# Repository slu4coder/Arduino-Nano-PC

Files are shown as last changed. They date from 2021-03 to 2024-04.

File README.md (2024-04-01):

# Arduino Nano Personal Computer - Squeezing Water from a Stone

I am pushing the limits of how much compute you can get out of an Arduino Nano:

        o 320x200 pixels of monochrome VGA output (optional: 16 row colors)

        o PS/2 keyboard readout

        o requires only 1(!) logic IC 74HC166

bild

# HOW TO USE THE 'NANO HOME COMPUTER'

1. Set the Nano's fuses for output of the 16MHz system clock on pin D8 (see appendix A below).

2. Copy the library files 'os.h' and 'os.S' into a folder '../Arduino/libraries/os'.

3. Start a new sketch with '#include <os.h>'. The following global variables and functions are available:

        int os::frames                                        built-in 16-bit 60Hz frame counter
  
        byte os::vram[25][40]                                 character video RAM array
  
        byte os::cram[25]                                     row color RAM array, available colors are:
  
                                                              WHITE, BLACK, GRAY, RED, GREEN, YELLOW, BLUE, MAGENTA, CYAN,
                                                    
                                                              DKGRAY, DKRED, DKGREEN, DKYELLOW, DKBLUE, DKMAGENTA, DKCYAN.
                                                    
        os::text(String s, byte x, byte y, byte col = 0)      prints text at screen position (x, y), col = 0: don't set row color
  
        os::fill(char c = 32)                                 fills the video RAM with character c
  
        os::scroll()                                          scrolls the video RAM one step upwards
  
        os::wait(int n)                                       waits for n frames
  
        byte os::getkey()                                     returns keystroke ASCII code (none: 0)
  
4. 26KB FLASH (1KB SRAM) of the Nano's 30KB FLASH (2KB SRAM) are usable, respectively.
   To save SRAM, define constant variables in FLASH memory by adding PROGMEM to the data type.
   Constant string arguments can be defined in FLASH by using the F("...") macro.

5. Have fun!

APPENDIX

A. Setting Arduino Nano's fuse bytes via ISP (in-situ programming) for output of system CLK

  o Connect two Arduino Nanos in the following way (programmer -> target):
    D13 -> D13, D12 -> D12, D11 -> D11, D10 -> RESET, 5V -> 5V, GND -> GND
    
  o Arduino IDE: Upload sketch 'examples/ArduinoISP' into programmer and select 'Tools/Programmer/Arduino as ISP'.
  
  o Open the file 'C:\Program Files (x86)\Arduino\hardware\arduino\avr\boards.txt'.
  
  o In section '## Arduino Nano w/ ATmega328P' (line 141), change line 149 'nano.menu.cpu.atmega328.bootloader.low_fuses=0xFF'
    (default) to '...=0xBF' (output system CLK on Pin D8 (B0)) and save the file.
    
  o Close and re-open the Arduino IDE for the changes to become active.
  
  o Select target board: 'Arduino Nano', processor: 'AtMega328P' and 'Tools/Burn bootloader'.

B. Hardware

  Pin A0 (C0):     keyboard input CLK
  
  Pin A1 (C1):     keyboard input DAT
  
  Pin A2-5 (C2-5): 4-bit color output to 74HC08 (optional)
  
  Pin D0-7 (D0-7): 8-bit pixel output to 74HC166
  
  Pin D8 (B0):     CLKO (16MHz system clock output)
  
  Pin D9 (B1):     unused
  
  Pin D10 (B2):    /VSYNC VGA (timer1, every 1/60s)
  
  Pin D11 (B3):    /PE 74166 pixel shift register synchroneous parallel load on rising edge of CP
  
  Pin D12 (B4):    /HSYNC VGA (inside ISR, every 32µs)
  
  Pin D13 (B5):    LED

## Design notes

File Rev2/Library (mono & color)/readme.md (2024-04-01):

# Header Library

Copy the folder 'os' containing the header library files to '/Arduino/libraries/'.

See 'Arduino IDE/File/Preferences' if you are unsure where to find it).
Be sure to start a new sketch with '#include <os.h>'.

Have fun!

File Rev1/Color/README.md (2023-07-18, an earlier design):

# Arduino Nano Personal Computer 1

16-color mod of my original 'Arduino Nano PC' revision 1 with VGA output and PS/2 keyboard input
running on a single Arduino NANO and 5 additional logic ICs.

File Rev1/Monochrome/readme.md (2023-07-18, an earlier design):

# Arduino Nano PC 1

Original monochrome version using 4 additional logic ICs.

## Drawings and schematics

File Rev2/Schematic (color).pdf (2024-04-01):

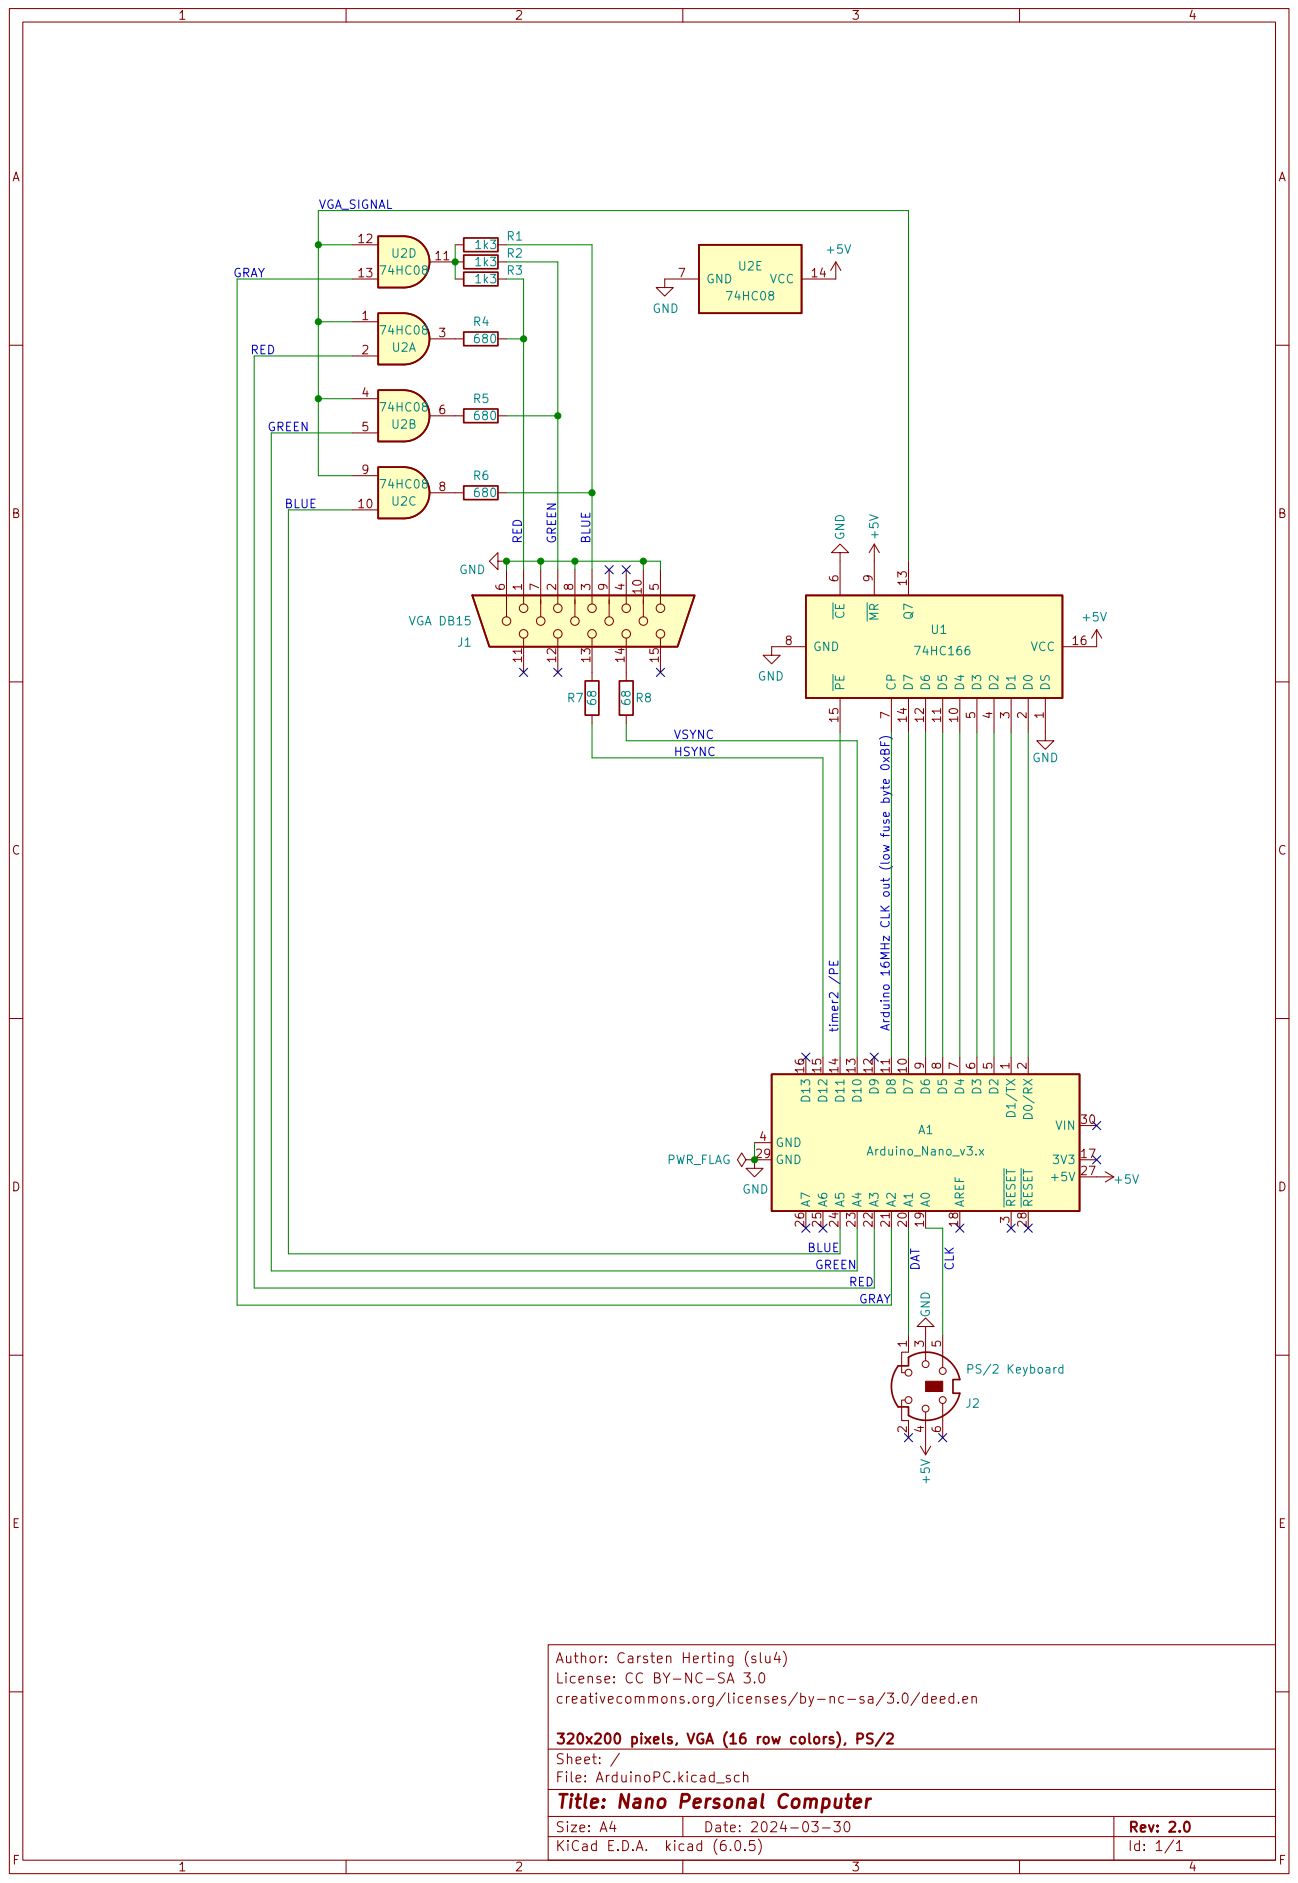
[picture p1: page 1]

2 A1 20 A2 21 A3 22 A4 23 A5 24 A6 25 A7 26 +5V 27 ~{RESET} 28 GND 29 ~{RESET} 3 VIN 30 GND 4 D2

License: CC BY-NC-SA 3.0 Author: Carsten Herting (slu4)

creativecommons.org/licenses/by-nc-sa/3.0/deed.en

File: ArduinoPC.kicad_sch Sheet: / 320x200 pixels, VGA (16 row colors), PS/2

Id: 1/1 Title: Nano Personal Computer

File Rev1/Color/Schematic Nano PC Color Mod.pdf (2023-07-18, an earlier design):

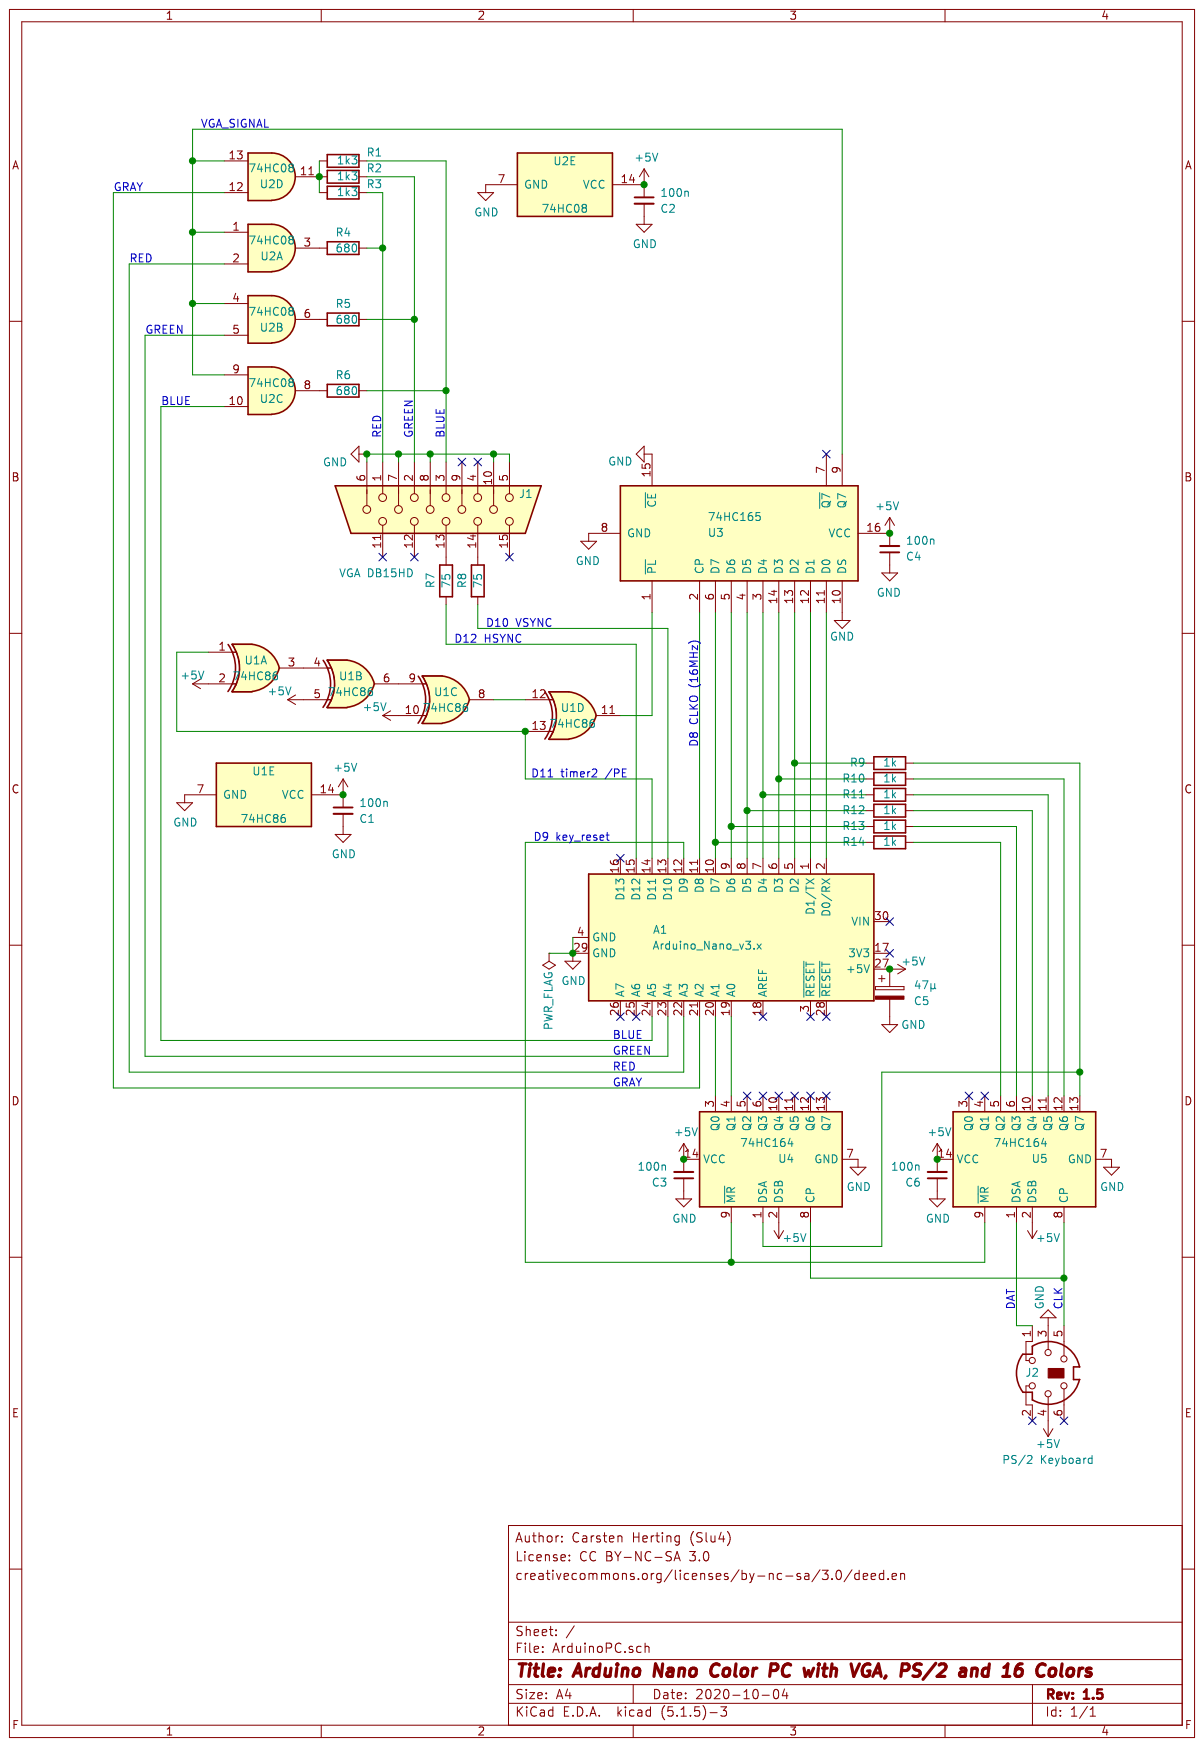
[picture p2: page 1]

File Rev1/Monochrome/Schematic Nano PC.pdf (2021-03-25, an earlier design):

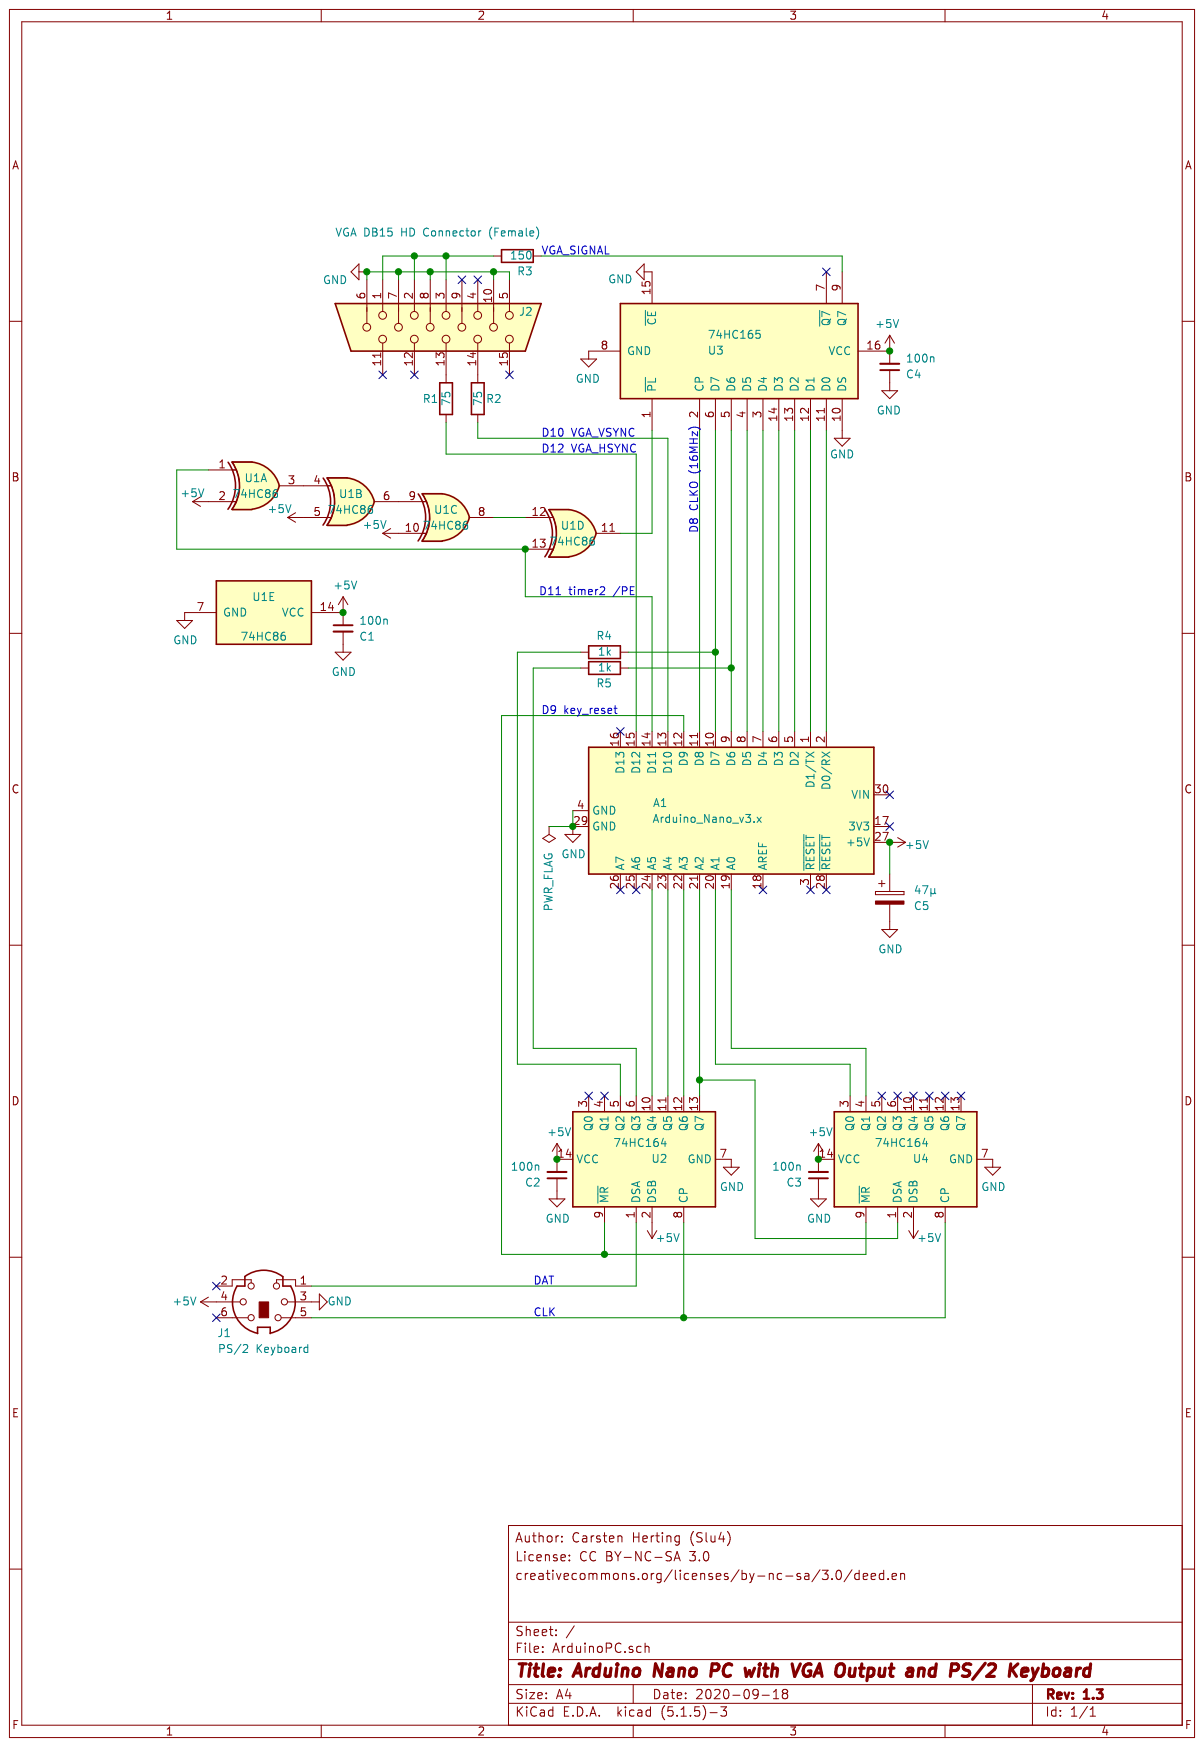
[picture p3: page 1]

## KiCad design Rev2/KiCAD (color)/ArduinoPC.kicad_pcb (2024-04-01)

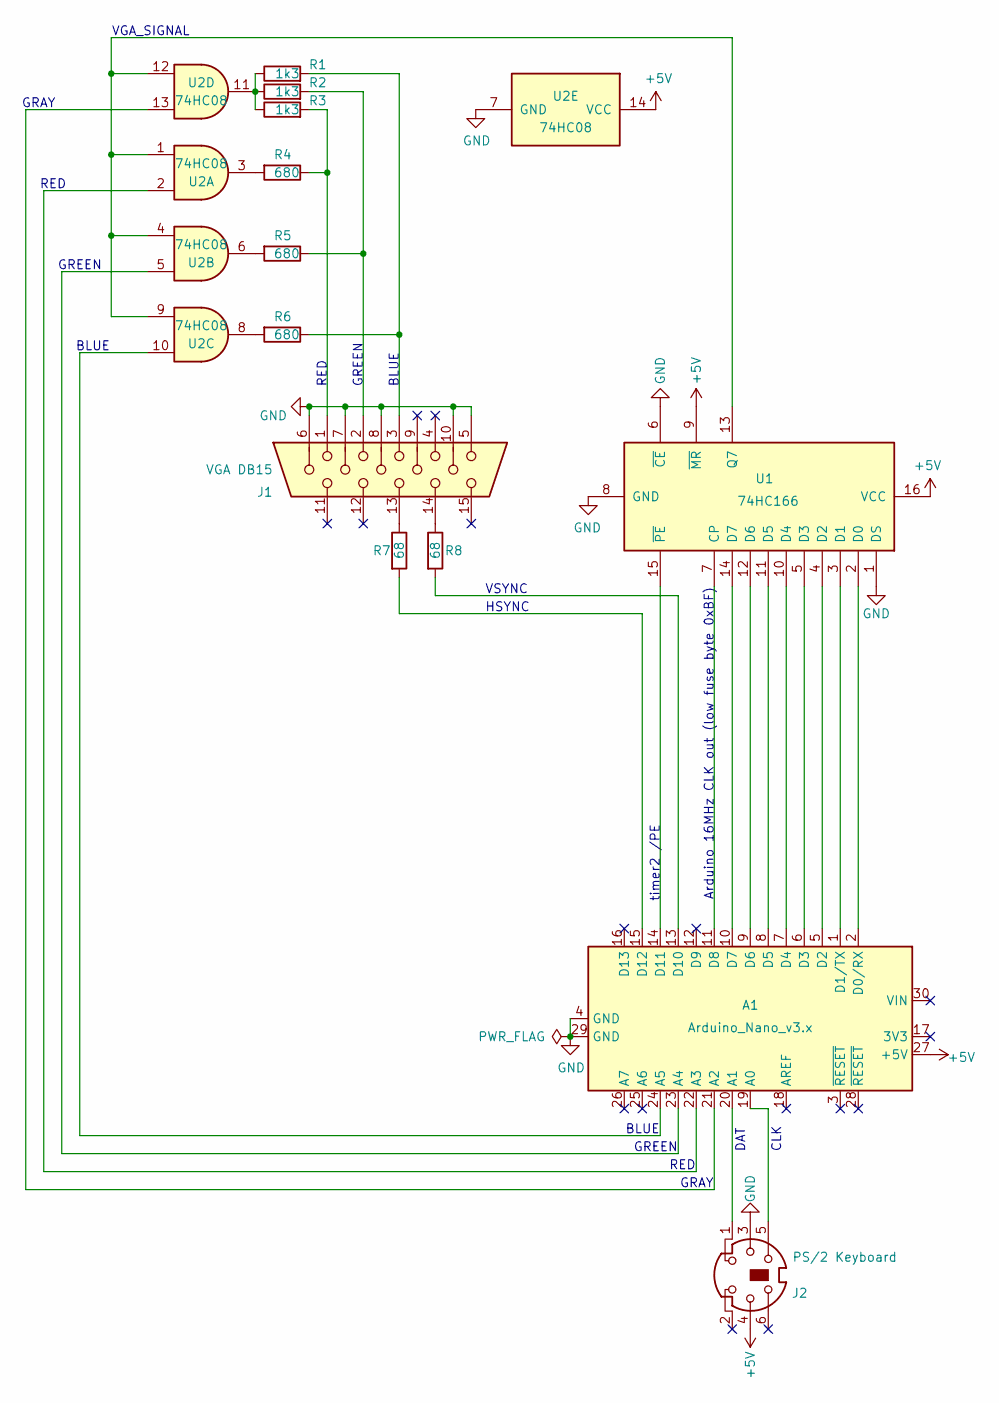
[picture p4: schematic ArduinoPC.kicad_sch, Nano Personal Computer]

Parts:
A1: Arduino_Nano_v3.x; Arduino_Nano
J1: VGA DB15; VGA DSUB15HD_female
J2: PS/2 Keyboard; FP_MINI_DIN_6_PS2
R1, R2, R3: 1k3; R_Axial_DIN0207_L6.3mm_D2.5mm_P2.54mm_Vertical
R4, R5, R6: 680; R_Axial_DIN0207_L6.3mm_D2.5mm_P2.54mm_Vertical
R7, R8: 68; R_Axial_DIN0207_L6.3mm_D2.5mm_P2.54mm_Vertical
U1: 74HC166; DIP-16_W7.62mm
U2: 74HC08; DIP-14_W7.62mm

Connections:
+5V: A1.27 (+5V), J2.4, U1.9 (~MR), U1.16 (VCC), U2.14 (VCC)
GND: A1.4 (GND), A1.29 (GND), J1.5, J1.6, J1.7, J1.8, J1.10, J2.3, U1.1 (DS), U1.6 (~CE), U1.8 (GND), U2.7 (GND)
unnamed: A1.1 (D1/TX), U1.3 (D1)
unnamed: A1.2 (D0/RX), U1.2 (D0)
unnamed: A1.5 (D2), U1.4 (D2)
unnamed: A1.6 (D3), U1.5 (D3)
unnamed: A1.7 (D4), U1.10 (D4)
unnamed: A1.8 (D5), U1.11 (D5)
unnamed: A1.9 (D6), U1.12 (D6)
unnamed: A1.10 (D7), U1.14 (D7)
unnamed: A1.11 (D8), U1.7 (CP)
unnamed: A1.13 (D10), R8.2
unnamed: A1.14 (D11), U1.15 (~PE)
unnamed: A1.15 (D12), R7.2
unnamed: A1.19 (A0), J2.5
unnamed: A1.20 (A1), J2.1
unnamed: A1.21 (A2), U2.13
unnamed: A1.22 (A3), U2.2
unnamed: A1.23 (A4), U2.5
unnamed: A1.24 (A5), U2.10
unnamed: J1.1, R3.2, R4.1
unnamed: J1.2, R2.2, R5.1
unnamed: J1.3, R1.2, R6.1
unnamed: J1.13, R7.1
unnamed: J1.14, R8.1
unnamed: R1.1, R2.1, R3.1, U2.11
unnamed: R4.2, U2.3
unnamed: R5.2, U2.6
unnamed: R6.2, U2.8
unnamed: U1.13 (Q7), U2.1, U2.4, U2.9, U2.12

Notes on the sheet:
GREEN
RED
BLUE
VGA_SIGNAL
GRAY
timer2 /PE
Arduino 16MHz CLK out (low fuse byte 0xBF)
CLK
DAT
VSYNC
HSYNC

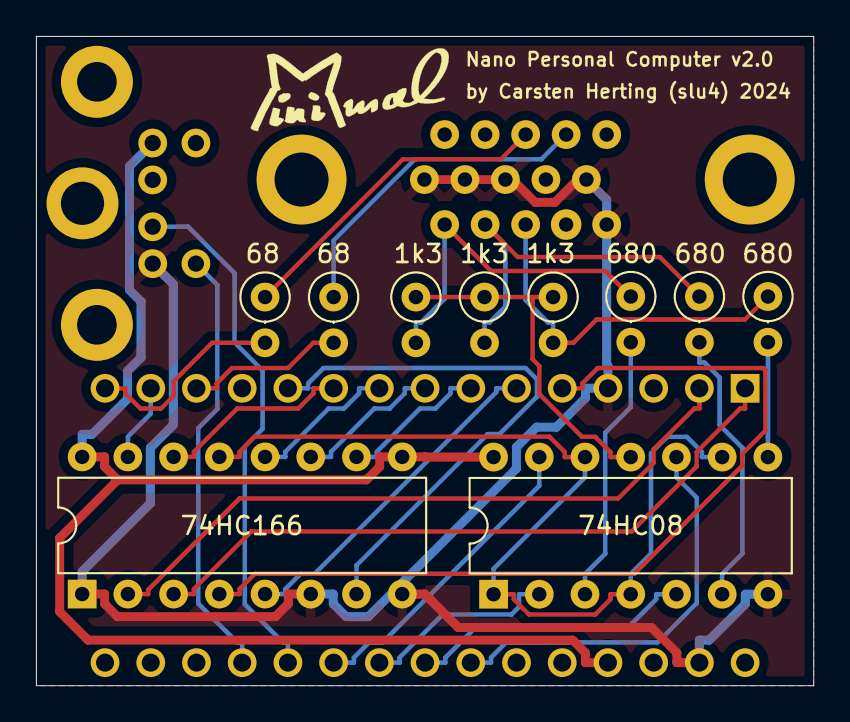
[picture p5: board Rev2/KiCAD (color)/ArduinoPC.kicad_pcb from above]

Board: 2 copper layers, 43.2 x 36.1 mm, 13 parts (0 on the bottom side), 30 nets.

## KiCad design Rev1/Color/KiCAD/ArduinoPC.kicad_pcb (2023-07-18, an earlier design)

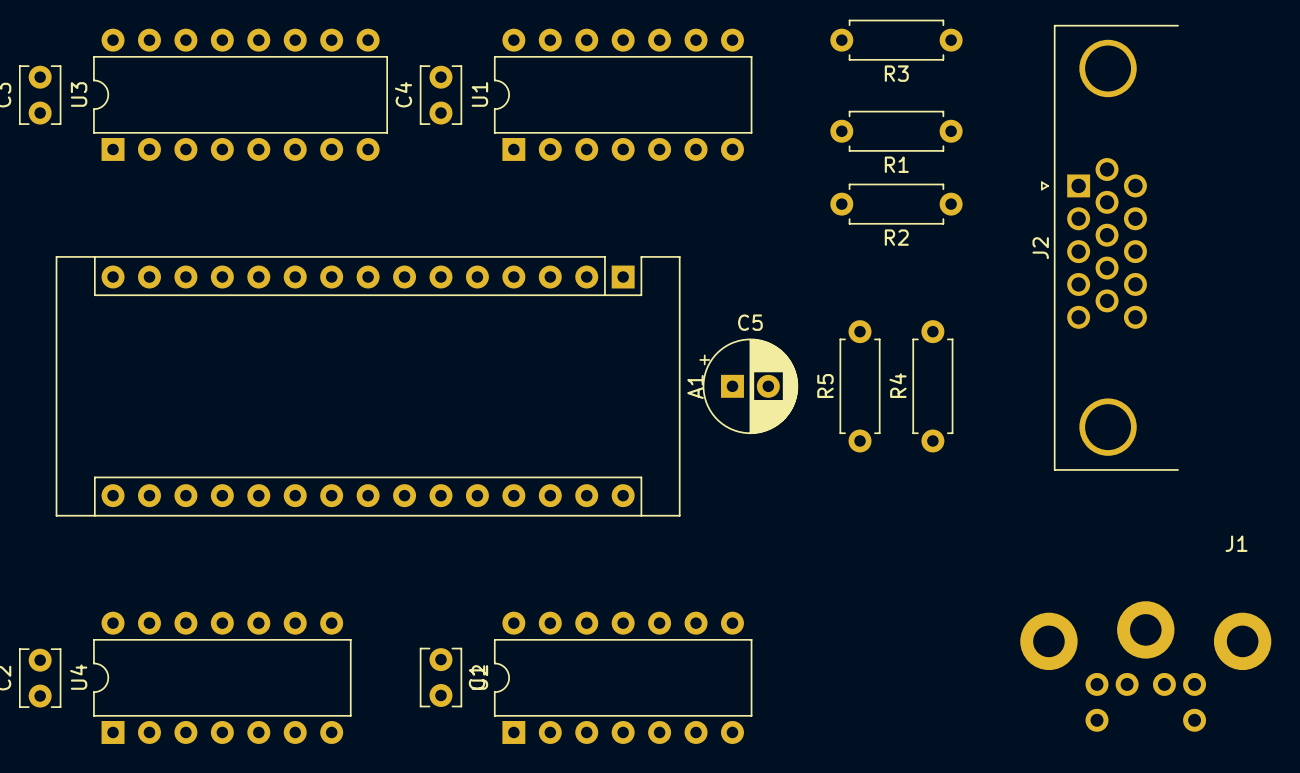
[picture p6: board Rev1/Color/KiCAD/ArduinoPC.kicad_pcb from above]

Board: 2 copper layers, 17 parts (0 on the bottom side), 33 nets, no tracks yet.

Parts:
A1: Arduino_Nano_v3.x; Arduino_Nano
C1, C2, C3, C4: 100n; C_Disc_D3.8mm_W2.6mm_P2.50mm
C5: 47µ; CP_Radial_D6.3mm_P2.50mm
J1: PS/2 Keyboard; FP_MINI_DIN_6_PS2
J2: VGA DB15 HD Connector (Female); DSUB-15-HD_Female_Horizontal_P2.29x1.98mm_EdgePinOffset3.03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
R1, R2: 68; R_Axial_DIN0207_L6.3mm_D2.5mm_P7.62mm_Horizontal
R3, R4, R5: 220; R_Axial_DIN0207_L6.3mm_D2.5mm_P7.62mm_Horizontal
U1: 74HC86; DIP-14_W7.62mm
U2, U4: 74HC164; DIP-14_W7.62mm
U3: 74HC165; DIP-16_W7.62mm

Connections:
+5V: A1.27, C1.1, C2.2, C3.2, C4.2, C5.1, J1.4, U1.2, U1.5, U1.10, U1.14, U2.2, U2.14, U3.16, U4.2, U4.14
GND: A1.4, A1.29, C1.2, C2.1, C3.1, C4.1, C5.2, J1.3, J2.5, J2.6, J2.7, J2.8, J2.10, U1.7, U2.7, U3.8, U3.10, U3.15, U4.7
unnamed: A1.1, U3.12
unnamed: A1.2, U3.11
unnamed: A1.5, U3.13
unnamed: A1.6, U3.14
unnamed: A1.7, U3.3
unnamed: A1.8, U3.4
unnamed: A1.9, R5.2, U3.5
unnamed: A1.10, R4.2, U3.6
unnamed: A1.11, U3.2
unnamed: A1.12, U2.9, U4.9
unnamed: A1.13, R2.2
unnamed: A1.14, U1.1, U1.13
unnamed: A1.15, R1.2
unnamed: A1.19, U4.4
unnamed: A1.20, U4.3
unnamed: A1.21, U2.13, U4.1
unnamed: A1.22, U2.12
unnamed: A1.23, U2.11
unnamed: A1.24, U2.10
unnamed: J1.1, U2.1
unnamed: J1.5, U2.8, U4.8
unnamed: J2.1, J2.2, J2.3, R3.1
unnamed: J2.13, R1.1
unnamed: J2.14, R2.1
unnamed: R3.2, U3.9
unnamed: R4.1, U2.5
unnamed: R5.1, U2.6
unnamed: U1.3, U1.4
unnamed: U1.6, U1.9
unnamed: U1.11, U3.1
unnamed: U1.8, U1.12

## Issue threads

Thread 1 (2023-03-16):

Working with 74HC166N shift register

PeterKL3, 2023-03-16:
Hi, thanks for the terrific work.
I want to ask you how I can use your code with the other shift register you sometimes use, the 74HC166. When I use it with this code and without the XOR-Gates, it displays only every other row on the VGA monitor. Is this a timing issues? Thanks a lot. Peter

slu4coder, 2023-07-22:
Hi Peter, the Nano PC Revision 1 relies on 74HC165. Please do not use 74HC166.

I am currently working on an update (Revision 2): 1x Nano + 1x 74HC166 = "full PC" with VGA and PS/2
Watch out for my upcoming YouTube video! Cheers!

Closed 2023-07-22.

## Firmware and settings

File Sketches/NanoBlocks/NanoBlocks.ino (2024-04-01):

#include <os.h> // copy the files 'os.h' and 'os.S' into the folder '.../Arduino/libraries/os'

char state, x, y, waiting;
int score, high = 0;
char shape[10];       // holding the current shape (with offset)
const char minos[7][10] PROGMEM = { { 0, 0, 1, 0, 0, -1, 1, -1,   0, 1 },     // Quadrat (with SRS offset)
                                    { -1, -1, 0, -1, 0, 0, 1, 0,  0, 0 },     // Z
                                    { -1, 0, 0, 0, 0, -1, 1, -1,  0, 0 },     // neg. Z
                                    { -1, 0, 0, 0, 1, 0, 2, 0,    0, 1 },     // I
                                    { -1, 0, 0, 0, 1, 0, 0, -1,   0, 0 },     // Podest
                                    { -1, -1, -1, 0, 0, 0, 1, 0,  0, 0 },     // L
                                    { -1, 0, 0, 0, 1, 0, 1, -1,   0, 0 }  };  // neg. L

void drawintro()
{
  os::fill();
  os::text(F("A R D U I N O   B L O C K S"), 6, 10, CYAN);
  os::text(F("Press  SPACE"), 13, 23, YELLOW);
}

void drawfield()
{
  os::fill();
  for (byte i=0; i<5; i++) os::text(F("<!..........!>"), 12, i, CYAN);
  for (byte i=5; i<20; i++) os::text(F("<!..........!>"), 12, i, WHITE);
  os::text(F("<!==========!>"), 12, 20, CYAN);
  os::text(F("  VVVVVVVVVV  "), 12, 21, MAGENTA);
  os::text(F("SCORE 0"), 0, 0, GREEN);
  os::text(F("HIGH"), 27, 0);    
  os::text(String(high, DEC), 32, 0);
  os::text(F("CONTROLS"), 0, 3, CYAN);
  os::text(F("A - Left"), 0, 5, GRAY);
  os::text(F("D - Right"), 0, 6, GRAY);
  os::text(F("W - Rotate"), 0, 7, GRAY);
  os::text(F("S - Drop"), 0, 8, GRAY);
}

boolean testShape(char x, char y)
{
  boolean isok = true;
  for (char i=0; i<8; i+=2)
  {
    if (x + shape[i] < 14+0 || x + shape[i] > 14+9) { isok = false; break; }         // linker / rechter Rand
    if (y + shape[i+1] < 0 || y + shape[i+1] > 19) { isok = false; break; }        // oberer / unterer Rand
    if (os::vram[y + shape[i+1]][x + shape[i]] != '.') { isok = false; break; }   // Spielfeld
  }
  return isok;
}

void newShape()
{
  byte m = random(7);
  for (char i=0; i<10; i++) shape[i] = pgm_read_byte_near(&minos[m][i]);
  x = 14+4; y = 1;
  if (testShape(x, y)) drawShape('#');
  else
  {
    os::text(F("GAME  OVER"), 14, 10, RED);
    os::text(F("Press  SPACE"), 13, 23, YELLOW);
    state = 2;
  }
}

void rotShape()
{
  char rotshape[10];
  for(char i=0; i<10; i+=2)
  {
    rotshape[i] = shape[i+1];
    rotshape[i+1] = -shape[i];
  }
  for (char i=0; i<10; i++) shape[i] = rotshape[i];
  x += shape[8]; y+= shape[9];  // add rotated offset correction
}

void drawShape(char c)
{
  for (char i=0; i<8; i+=2) os::vram[y + shape[i+1]][x + shape[i]] = c;        // Shape ins Feld schreiben  
}

void updateField()
{
  char anzrows = 0;                                                             // count the number of rows cleared
  for (char y=0; y<20; y++)                                                    // gehe alle Reihen durch
  {
    boolean rowfull = true;
    for(char x=14; x<14+10; x++) if (os::vram[y][x] == '.') rowfull = false;            // ist diese Reihe voll?
    if (rowfull)
    {
      anzrows++;
      for(char i=y; i>0; i--) for(char x=14; x<14+10; x++) os::vram[i][x] = os::vram[i-1][x];   // kopiere ab dieser Reihe alles nach unten
      for(char x=14; x<14+10; x++) os::vram[0][x] = '.';                                      // und lösche die obere Zeile
    }
  }
  switch (anzrows)
  {
    case 1: score += 40; break;
    case 2: score += 100; break;
    case 3: score += 200; break;
    case 4: score += 500; break;
  }
}

void setup()
{
  drawintro();
  state = 0;
}

void loop()
{ 
  int frame = os::frames;
  byte key = os::getkey();
  switch(state)
  {
    case 0:
      if (key == ' ')
      {
        randomSeed(os::frames); random();
        drawfield();
        newShape();
        waiting = 40; os::frames = 0; score = 0; state = 1;

      }
      break;
    case 1:
      if (key != 0)
      {
        if (key == 's') { waiting -= 40; score++; }
        else
        {
          drawShape('.');        // Shape ins Feld schreiben  
          switch (key)
          {
            case 'a':
              if (testShape(x-1, y)) x--;
              break;
            case 'd':
              if (testShape(x+1, y)) x++;
              break;
            case 'w':
              rotShape();                                               // drehe die Shape ccw
              if (testShape(x, y) == false)                             // prüfe, ob darunter KEIN Platz ist
              {
                if (testShape(x-1, y)) x--;                             // teste links
                else if (testShape(x+1, y)) x++;                        // teste rechts
                else if (testShape(x-2, y)) x-=2;                       // Sonderfall langer Balken
                else if (testShape(x+2, y)) x+=2;
                else { rotShape(); rotShape(); rotShape(); }            // geht nicht => Drehung rückgängig machen          
              }
              break;            
          }
          drawShape('#');        // Shape ins Feld schreiben  
        }
      }
      if (waiting-- < 0)                                          // FALLEN
      {
        waiting += (40 - (os::frames >> 9));
        drawShape('.');
        if (testShape(x, y+1)) { y++; drawShape('#'); }
        else
        {
          drawShape('#');                   // fix shape
          updateField();                    // clear full rows
          os::text(String(score, DEC), 6, 0);          
          if (score > high) { high = score; os::text(String(high, DEC), 32, 0); }
          newShape();                       // pick a new shape if possible
          drawShape('#');
        }
      }  
      break;
    case 2:
      if (key == ' ') { drawintro(); state = 0; }
      break;
  }
  while (frame == os::frames);
}

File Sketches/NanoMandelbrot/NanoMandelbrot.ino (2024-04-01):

// ------------------------------------------------------------------------
// Displays the 'Mandelbrot' set by projecting the area (-2.5..1) * (-1..1)
// onto 32 x 22 pixels using a maximum of 15 iterations and 32-bit integer
// math in 9-bit fixed-point format  -    written by C. Herting (slu4) 2024
// ------------------------------------------------------------------------
#include <os.h> // copy the files 'os.h' and 'os.S' into the folder '.../Arduino/libraries/os'

void setup() { os::fill(); } // clear the screen

void loop()
{      
  long cb = -506; // -1
  for (byte y=0; y<22; y++)
  {
    long ca = -1288; // -2.5
    for (byte x=0; x<32; x++)
    {
      long za = ca; // init start condition
      long zb = cb;
      byte n;
      
      for (n=15; n>0; n--) // iterate f(z) = z^2 + c
      {
        long za_sq = (za * za) >> 9;
        long zb_sq = (zb * zb) >> 9;
        if (za_sq + zb_sq >= (4 << 9)) break; // diverging if z^2 >= 4
        zb = (((za * zb) >> 9) << 1) + cb; // zb = za*zb + cb
        za = za_sq - zb_sq + ca; // za = za^2 - zb^2 + ca
      }
      os::vram[y][x] = ' ' + n; // plot current pixel
      ca += 56;
    }
    cb += 46;
  }
}

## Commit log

2020-09-22 Initial release
    [ArduinoPC.kicad_pcb, ArduinoPC.sch]
2020-10-20 minor optimizations in some resistor values
2021-04-16 Fixing jitter compensation on some monitors
    [os.h]
